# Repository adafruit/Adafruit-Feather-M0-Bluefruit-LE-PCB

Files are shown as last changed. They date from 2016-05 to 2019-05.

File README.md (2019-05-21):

## Adafruit Feather M0 Bluefruit LE PCB
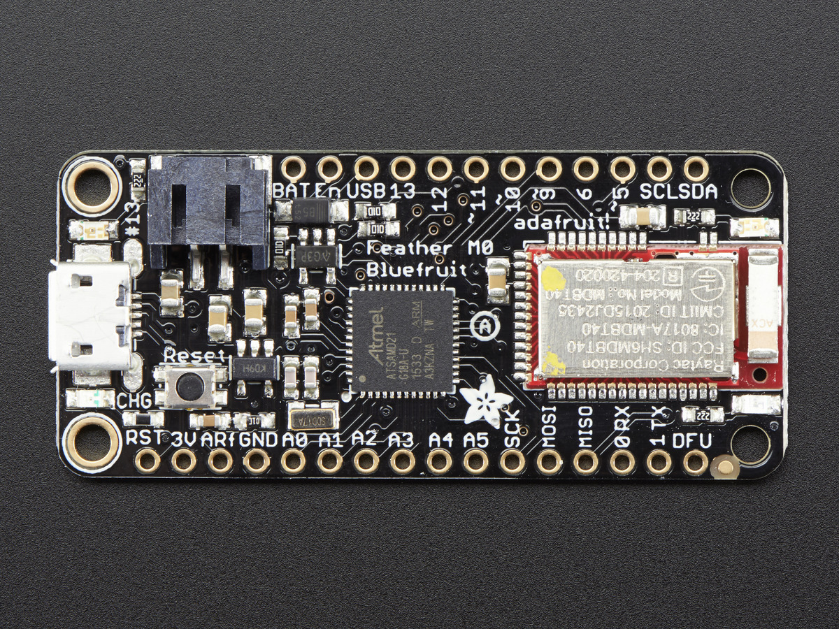
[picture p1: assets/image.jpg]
<a href="http://www.adafruit.com/products/2995"><br/>
Click here to purchase one from the Adafruit shop</a>

This is the Adafruit Feather M0 Bluefruit LE - our take on an 'all-in-one' Arduino-compatible + Bluetooth Low Energy with built in USB and battery charging. It's an Adafruit Feather M0 with a BTLE module, ready to rock! We have other boards in the Feather family, check'em out here.

Bluetooth Low Energy is a hot, low-power, 2.4GHz spectrum wireless protocol. In particular, it's the only wireless protocol that you can use with iOS without needing special certification, and it's supported by all modern smart phones. This makes it excellent for use in portable projects that will make use of an iOS or Android phone or tablet. It also is supported in Mac OS X and Windows 8+.

At the Feather M0's heart is an ATSAMD21G18 ARM Cortex M0 processor, clocked at 48 MHz and at 3.3V logic, the same one used in the new Arduino Zero. This chip has a whopping 256K of FLASH (8x more than the Atmega328 or 32u4) and 32K of RAM (16x as much)! This chip comes with built in USB so it has USB-to-Serial program & debug capability built in with no need for an FTDI-like chip.

PCB files for the Adafruit Feather M0 Bluefruit LE PCB. The format is EagleCAD schematic and board layout
- https://www.adafruit.com/product/2995

### License

Adafruit invests time and resources providing this open source design, please support Adafruit and open-source hardware by purchasing products from [Adafruit](https://www.adafruit.com)!

All text above must be included in any redistribution

Designed by Limor Fried/Ladyada for Adafruit Industries.
Creative Commons Attribution/Share-Alike, all text above must be included in any redistribution. 
See license.txt for additional information.

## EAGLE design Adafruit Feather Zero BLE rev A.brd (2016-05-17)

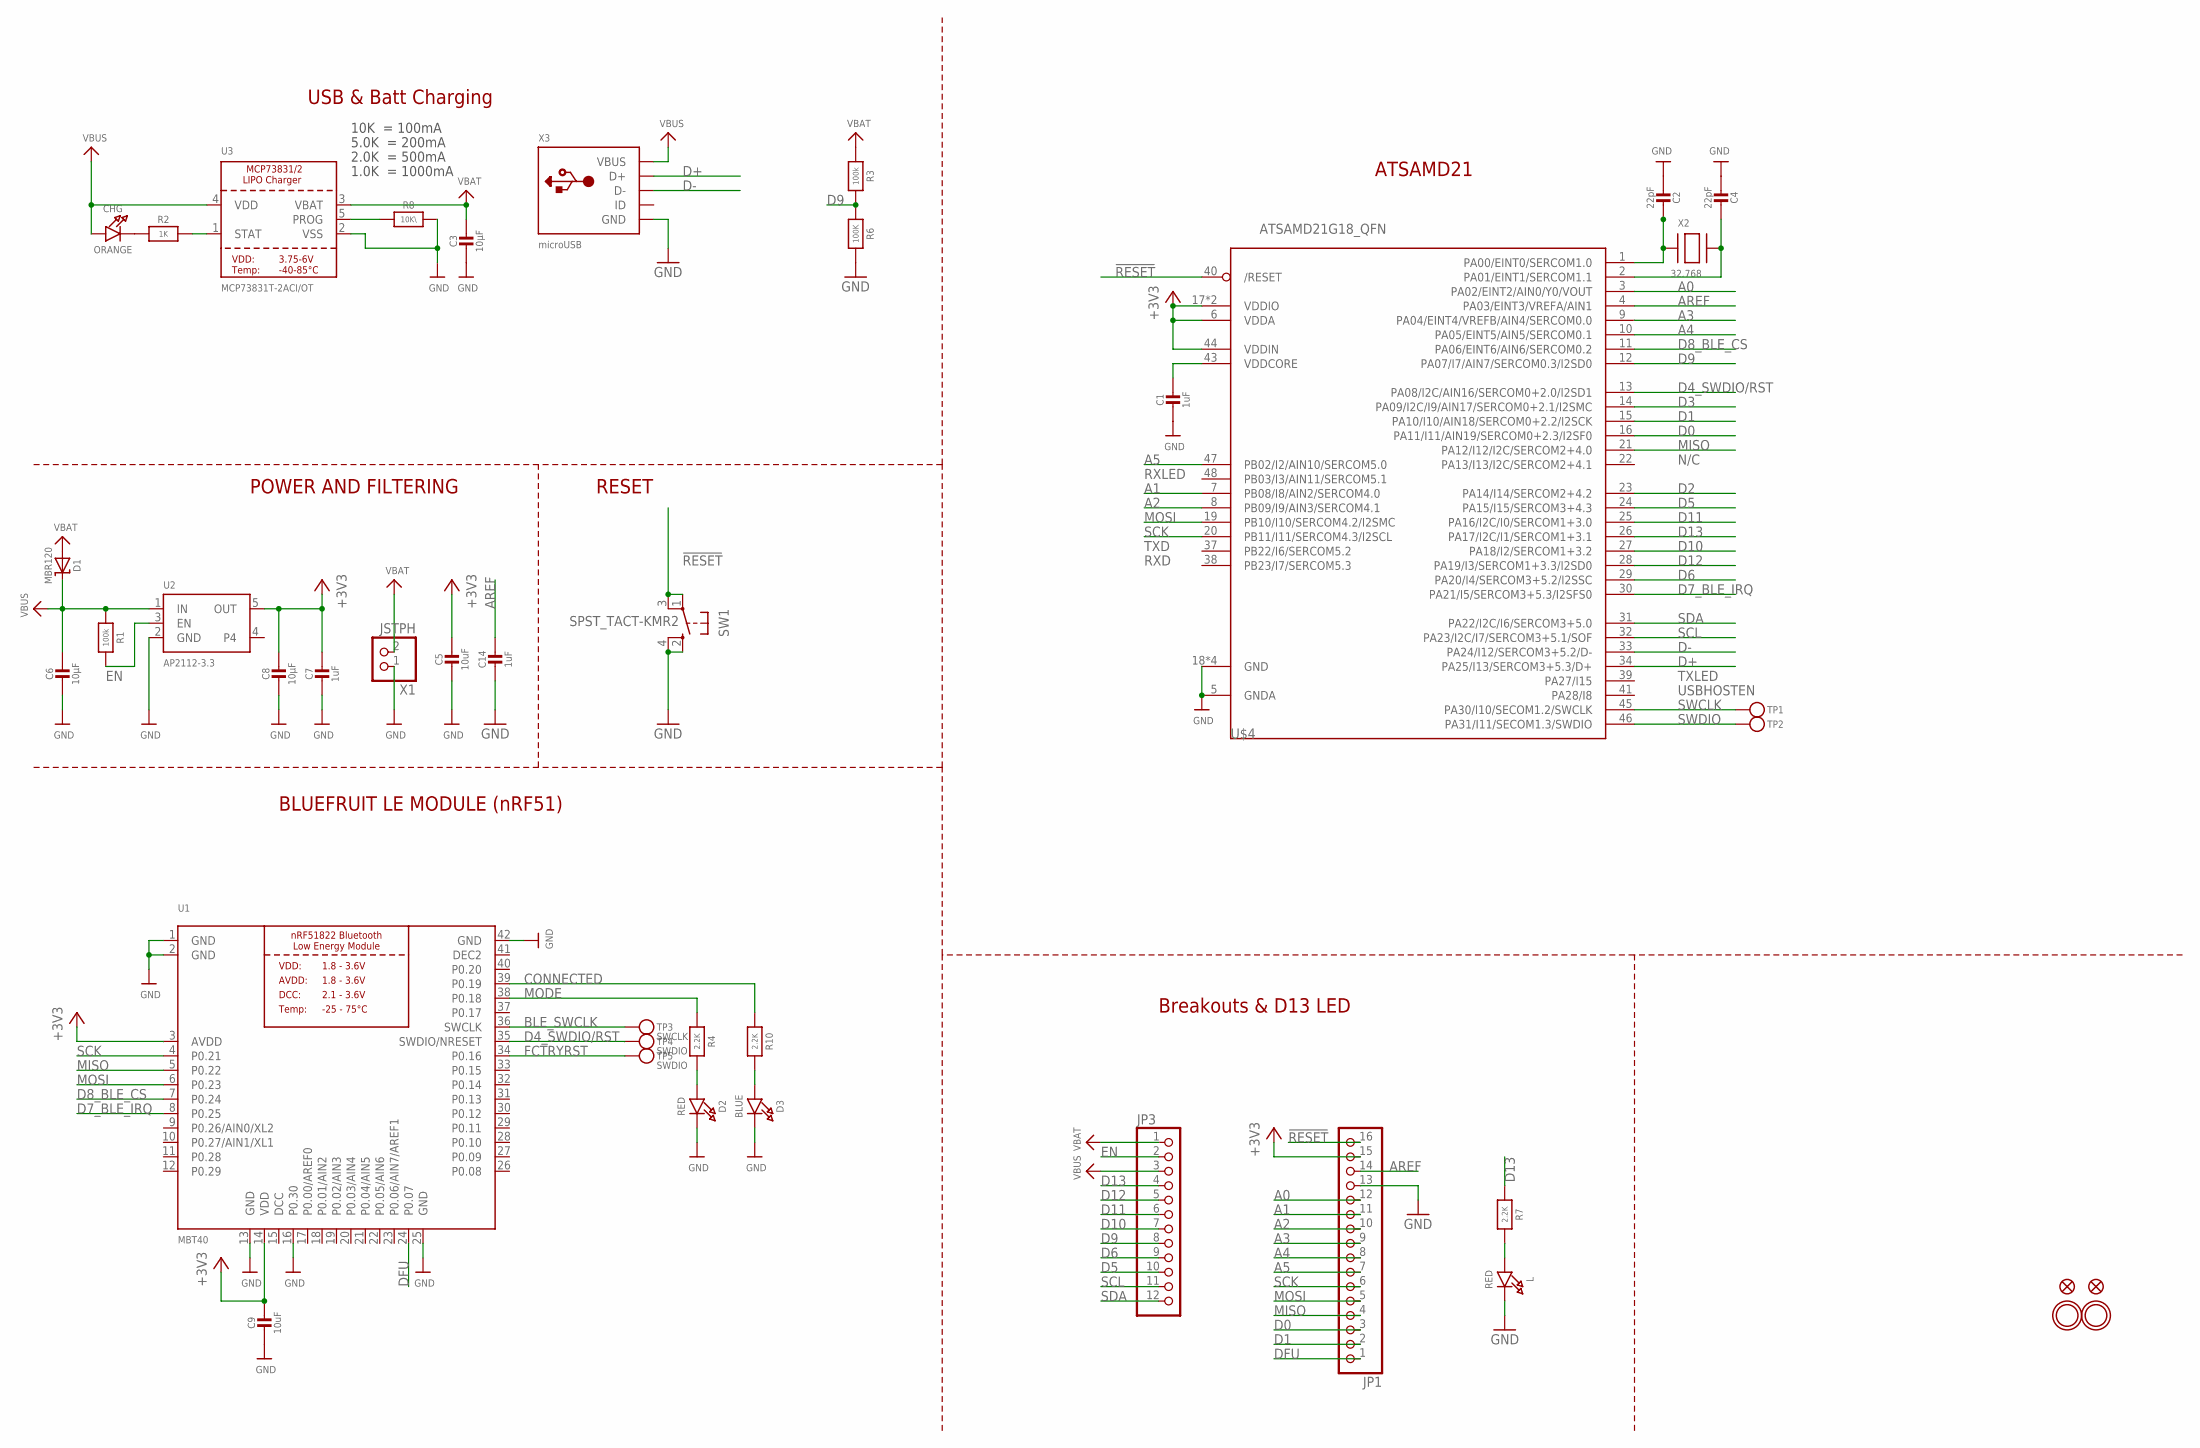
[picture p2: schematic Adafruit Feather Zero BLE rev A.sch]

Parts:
C1, C7, C14: 1uF; 0603-NO
C2, C4: 22pF; 0603-NO
C3, C6, C8: 10µF; 0805-NO
C5, C9: 10uF; 0805-NO
CHG: ORANGE; CHIPLED_0805_NOOUTLINE
D1: MBR120; SOD-123
D2: RED; CHIPLED_0805_NOOUTLINE
D3: BLUE; CHIPLED_0805_NOOUTLINE
JP1: HEADER-1X16ROUND; 1X16_ROUND
JP3: HEADER-1X12; 1X12_ROUND
L: RED; CHIPLED_0805_NOOUTLINE
R1, R3: 100k; 0603-NO
R2: 1K; 0603-NO
R4, R7, R10: 2.2K; 0603-NO
R6: 100K; 0603-NO
R8: 10K\; 0603-NO
SW1: SPST_TACT-KMR2; KMR2
TP1, TP2: TESTPOINTROUND1.5MM; TESTPOINT_ROUND_1.5MM
TP3: SWCLK; PAD-1.5X2.0
TP4, TP5: SWDIO; PAD-1.5X2.0
U1: MBT40; BLE_MODULE_RAYTAC_MDBT40
U2: AP2112-3.3; SOT23-5
U3: MCP73831T-2ACI/OT; SOT23-5
U$4: ATSAMD21G18_QFN; TQFN48_7MM
U$31, U$32: MOUNTINGHOLE2.5; MOUNTINGHOLE_2.5_PLATED
U$34, U$35: FIDUCIAL""; FIDUCIAL_1MM
X1: JSTPH; JSTPH2
X2: 32.768; XTAL3215
X3: microUSB; 4UCONN_20329_V2

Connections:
!RESET: JP1.16, SW1.1, SW1.3 (P1), U$4.40 (/RESET)
+3V3: C5.1, C7.1, C8.1, C9.1, JP1.15, U1.3 (AVDD), U1.14 (VDD), U2.5 (OUT), U$4.6 (VDDA), U$4.17 (VDDIO), U$4.36 (VDDIO), U$4.44 (VDDIN)
A0: JP1.12, U$4.3 (PA02/EINT2/AIN0/Y0/VOUT)
A1: JP1.11, U$4.7 (PB08/I8/AIN2/SERCOM4.0)
A2: JP1.10, U$4.8 (PB09/I9/AIN3/SERCOM4.1)
A3: JP1.9, U$4.9 (PA04/EINT4/VREFB/AIN4/SERCOM0.0)
A4: JP1.8, U$4.10 (PA05/EINT5/AIN5/SERCOM0.1)
A5: JP1.7, U$4.47 (PB02/I2/AIN10/SERCOM5.0)
AREF: C14.1, JP1.14, U$4.4 (PA03/EINT3/VREFA/AIN1)
BLE_SWCLK: TP3.P$1, U1.36 (SWCLK)
CONNECTED: R10.1, U1.39 (P0.19)
D0: JP1.3, U$4.16 (PA11/I11/AIN19/SERCOM0+2.3/I2SF0)
D1: JP1.2, U$4.15 (PA10/I10/AIN18/SERCOM0+2.2/I2SCK)
D2: U$4.23 (PA14/I14/SERCOM2+4.2)
D3: U$4.14 (PA09/I2C/I9/AIN17/SERCOM0+2.1/I2SMC)
D4_SWDIO/RST: TP4.P$1, U1.35 (SWDIO/NRESET), U$4.13 (PA08/I2C/AIN16/SERCOM0+2.0/I2SD1)
D5: JP3.10, U$4.24 (PA15/I15/SERCOM3+4.3)
D6: JP3.9, U$4.29 (PA20/I4/SERCOM3+5.2/I2SSC)
D7_BLE_IRQ: U1.8 (P0.25), U$4.30 (PA21/I5/SERCOM3+5.3/I2SFS0)
D8_BLE_CS: U1.7 (P0.24), U$4.11 (PA06/EINT6/AIN6/SERCOM0.2)
D9: JP3.8, R3.2, R6.1, U$4.12 (PA07/I7/AIN7/SERCOM0.3/I2SD0)
D10: JP3.7, U$4.27 (PA18/I2/SERCOM1+3.2)
D11: JP3.6, U$4.25 (PA16/I2C/I0/SERCOM1+3.0)
D12: JP3.5, U$4.28 (PA19/I3/SERCOM1+3.3/I2SD0)
D13: JP3.4, R7.1, U$4.26 (PA17/I2C/I1/SERCOM1+3.1)
D+: U$4.34 (PA25/I13/SERCOM3+5.3/D+), X3.D+
D-: U$4.33 (PA24/I12/SERCOM3+5.2/D-), X3.D-
DCC: U1.15 (DCC)
DEC2: U1.41 (DEC2)
DFU: JP1.1, U1.24 (P0.07)
EN: JP3.2, R1.2, U2.3 (EN)
FCTRYRST: TP5.P$1, U1.34 (P0.16)
GND: C1.2, C2.2, C3.2, C4.2, C5.2, C6.2, C7.2, C8.2, C9.2, C14.2, D2.C, D3.C, JP1.13, L.C, R6.2, R8.2, SW1.2 (S), SW1.4 (S1), U1.1 (GND), U1.2 (GND), U1.13 (GND), U1.16 (P0.30), U1.25 (GND), U1.42 (GND), U2.2 (GND), U3.2 (VSS), U$4.5 (GNDA), U$4.18 (GND), U$4.35 (GND), U$4.42 (GND), U$4.THERMAL (GND), X1.1, X3.BASE@1 (GND), X3.BASE@2 (GND), X3.GND, X3.SPRT@1 (GND), X3.SPRT@2 (GND), X3.SPRT@3 (GND), X3.SPRT@4 (GND)
MISO: JP1.4, U1.5 (P0.22), U$4.21 (PA12/I12/I2C/SERCOM2+4.0)
MODE: R4.1, U1.38 (P0.18)
MOSI: JP1.5, U1.6 (P0.23), U$4.19 (PB10/I10/SERCOM4.2/I2SMC)
unnamed: CHG.C, R2.1
unnamed: L.A, R7.2
unnamed: R2.2, U3.1 (STAT)
unnamed: R8.1, U3.5 (PROG)
unnamed: C2.1, U$4.1 (PA00/EINT0/SERCOM1.0), X2.P$1
unnamed: D2.A, R4.2
unnamed: C4.1, U$4.2 (PA01/EINT1/SERCOM1.1), X2.P$2
unnamed: D3.A, R10.2
SCK: JP1.6, U1.4 (P0.21), U$4.20 (PB11/I11/SERCOM4.3/I2SCL)
SCL: JP3.11, U$4.32 (PA23/I2C/I7/SERCOM3+5.1/SOF)
SDA: JP3.12, U$4.31 (PA22/I2C/I6/SERCOM3+5.0)
SWCLK: TP1.P$1, U$4.45 (PA30/I10/SECOM1.2/SWCLK)
SWDIO: TP2.P$1, U$4.46 (PA31/I11/SECOM1.3/SWDIO)
VBAT: C3.1, D1.A, JP3.1, R3.1, U3.3 (VBAT), X1.2
VBUS: C6.1, CHG.A, D1.C, JP3.3, R1.1, U2.1 (IN), U3.4 (VDD), X3.VBUS
VDDCORE: C1.1, U$4.43 (VDDCORE)

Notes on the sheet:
POWER AND FILTERING
RESET
10K = 100mA
5.0K = 200mA
2.0K = 500mA
1.0K = 1000mA
N/C
TXLED
USBHOSTEN
RXLED
TXD
RXD
BLUEFRUIT LE MODULE (nRF51)
ATSAMD21
USB & Batt Charging
Breakouts & D13 LED

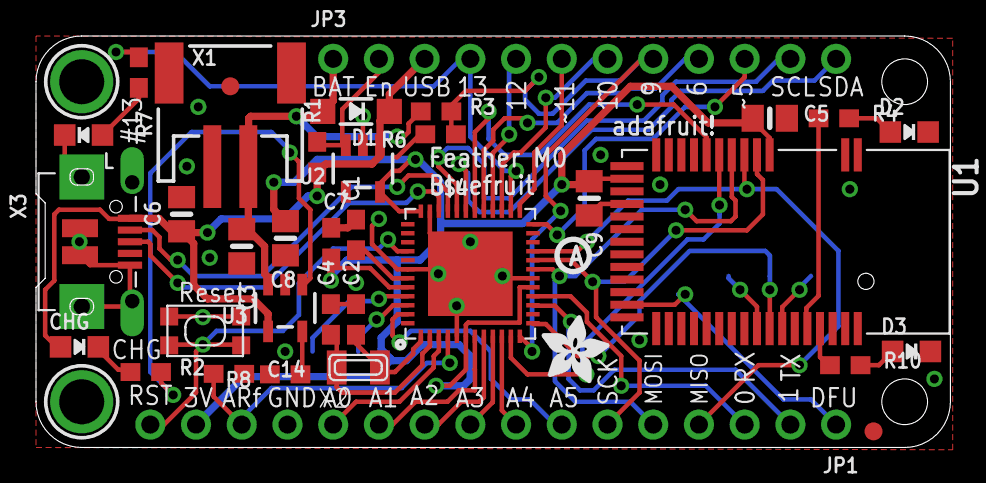
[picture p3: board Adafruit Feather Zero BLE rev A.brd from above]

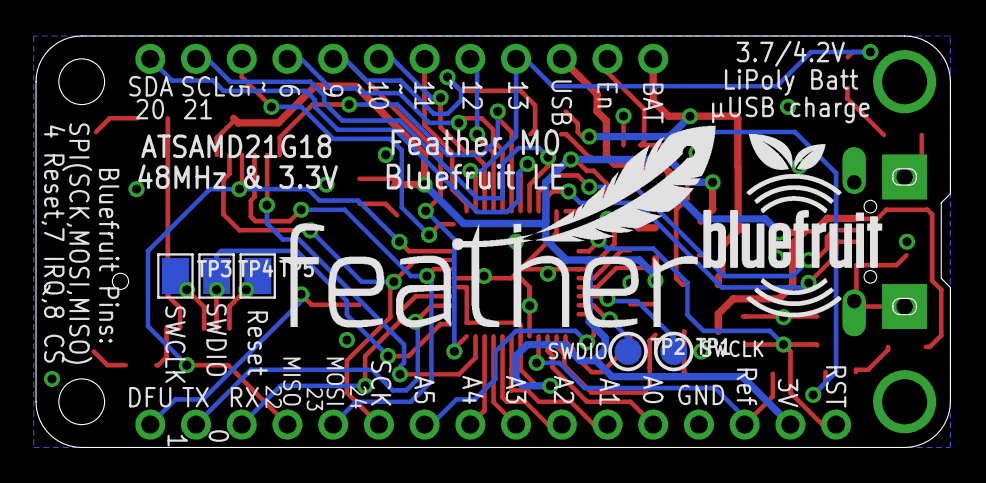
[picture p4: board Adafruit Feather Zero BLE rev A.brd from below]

Board: 2 copper layers, 50.8 x 22.9 mm, 46 parts (7 on the bottom side), 48 nets.

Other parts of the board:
U$7: ADAFRUIT_3.5MM
U$9: FEATHERLOGO
U$25: PCBFEAT-REV-040
U$26: BLUEFRUITLOGO_100MM

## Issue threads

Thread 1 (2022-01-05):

Error compiling for board adafruit feather m0

Constance-Balaam, 2022-01-05:
Hello I have been following this project. https://makezine.com/projects/led-matrix-handbag/
I am up to step 17 where I am having issues, I have downloaded the libraries it says necessary and made sure arduino is using the correct port and board. However, when uploading the BlueFruitConfig.h code : https://github.com/geekmomprojects/woven-led-handbag/blob/master/led_matrix_handbag/BluefruitConfig.h
I get this error and cannot figure out why.

Arduino: 1.8.16 (Mac OS X), Board: "Adafruit Feather M0, Small (-Os) (standard), Arduino, Off"

/Users/conniebalaam/Library/Arduino15/packages/adafruit/tools/arm-none-eabi-gcc/9-2019q4/bin/../lib/gcc/arm-none-eabi/9.2.1/../../../../arm-none-eabi/bin/ld: ../arduino_cache_81498/core/core_2f08c6f201c5d2959d88e155028a29c2.a(main.cpp.o): in function `main':
/Users/conniebalaam/Library/Arduino15/packages/adafruit/hardware/samd/1.7.5/cores/arduino/main.cpp:50: undefined reference to `setup'
/Users/conniebalaam/Library/Arduino15/packages/adafruit/tools/arm-none-eabi-gcc/9-2019q4/bin/../lib/gcc/arm-none-eabi/9.2.1/../../../../arm-none-eabi/bin/ld: /Users/conniebalaam/Library/Arduino15/packages/adafruit/hardware/samd/1.7.5/cores/arduino/main.cpp:54: undefined reference to `loop'
collect2: error: ld returned 1 exit status
exit status 1
Error compiling for board Adafruit Feather M0.

This report would have more information with
"Show verbose output during compilation"
option enabled in File -> Preferences.

any advice would be appreciated thank you, I am a student and very new to this :)

ladyada, 2022-01-15:
hi yes you need to post in arduino or adafruit forums to learn how to compile code :)

Closed 2022-01-15.

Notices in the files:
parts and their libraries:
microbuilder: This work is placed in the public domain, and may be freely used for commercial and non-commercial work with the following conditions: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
